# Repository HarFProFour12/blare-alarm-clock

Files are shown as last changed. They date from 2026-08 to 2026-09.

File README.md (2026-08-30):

# BLARE Alarm Clock

This is my custom alarm clock built using a Seeed XIAO ESP32C3 as the brain, with a customizable menu system, real-time clock over wifi, and public domain alarm melodies (Fur Elise, Mountain King, Reveille) played using a passive buzzer.

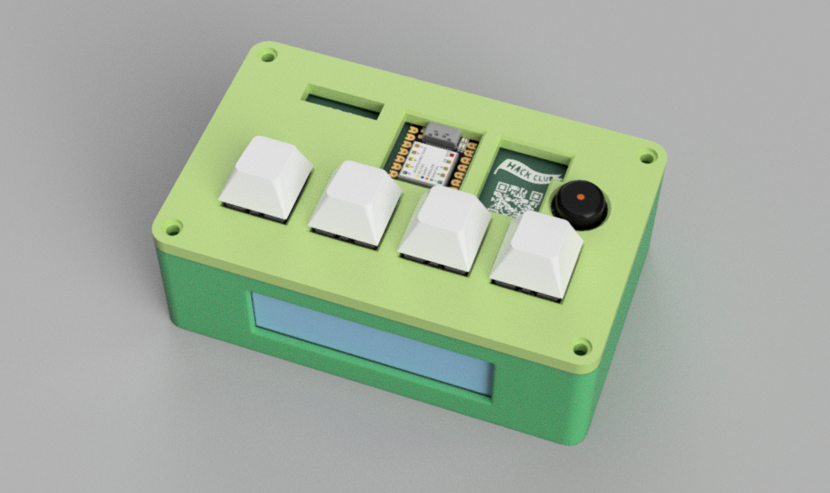
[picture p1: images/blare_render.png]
BLARE (render)


## Features

* RTC using Wi-Fi (NTP)
* Adjustable alarm time
* Changeable alarm sounds
* Adjustable font color
* Button-controlled UI
*  2.25in TFT Screen

## UI

The UI is designed using simple menus so it's easier to navigate using only four buttons (enter, back, up, down). 

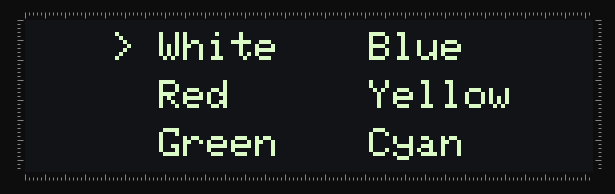
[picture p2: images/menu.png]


The Home screen displays the current time.

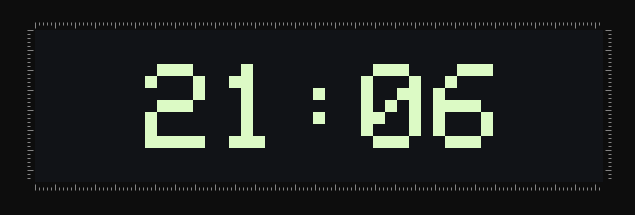
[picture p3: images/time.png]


The Settings menu currently has:

* Alarm Time
* Alarm Sound
* Font Color

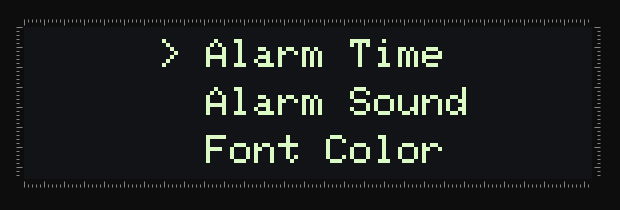
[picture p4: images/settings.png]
Settings Page UI


## How It Works

The clock is controlled by a Seeed XIAO ESP32C3. On startup, it connects to the wifi and get the current time through NTP, since I couldn't use an RTC module (all available GPIO pins were already being used). The current time is displayed on the Home screen, and the user can set the alarm time through the Settings menu. When the current time is the same as the alarm time, the selected melody is played using the piezo buzzer.

## Hardware

The current hardware includes the following components:

* Seeed XIAO ESP32C3
* 2.25in TFT Screen (ST7789 driver)
* 4 pushbuttons
* Passive piezo buzzer

## Schematic & Hardware Wiring

The board uses the XIAO ESP32-C3's D0–D10 pins for all peripherals:

* D0–D3: pushbuttons (enter, back, up, down)
* D4–D6, D8–D10: TFT screen (DC, CS, BL, RST, SCL, SDA)
* D7: buzzer

All 11 available GPIOs are used, leaving no free pins for other components such as an RTC module.

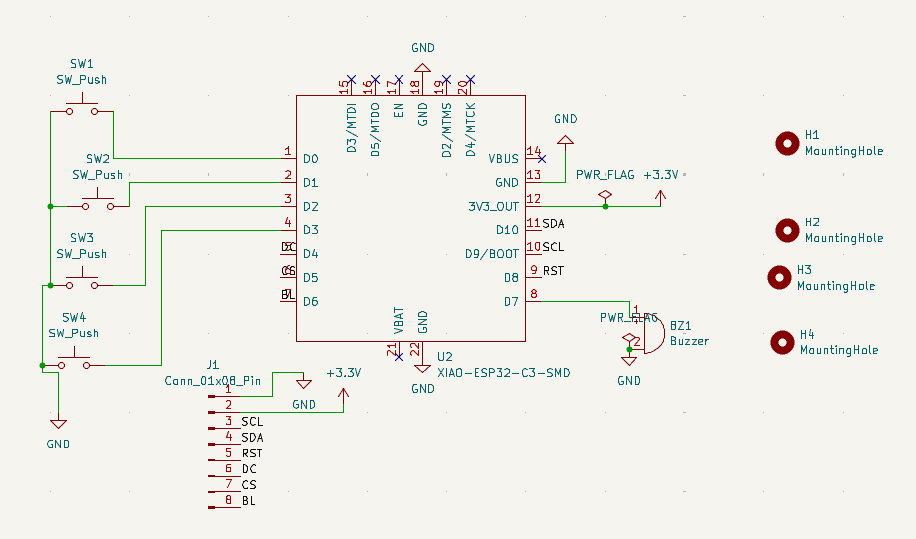
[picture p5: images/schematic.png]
Schematic


The PCB was designed in KiCad, with the four pushbuttons placed alongside the screen for easy access.

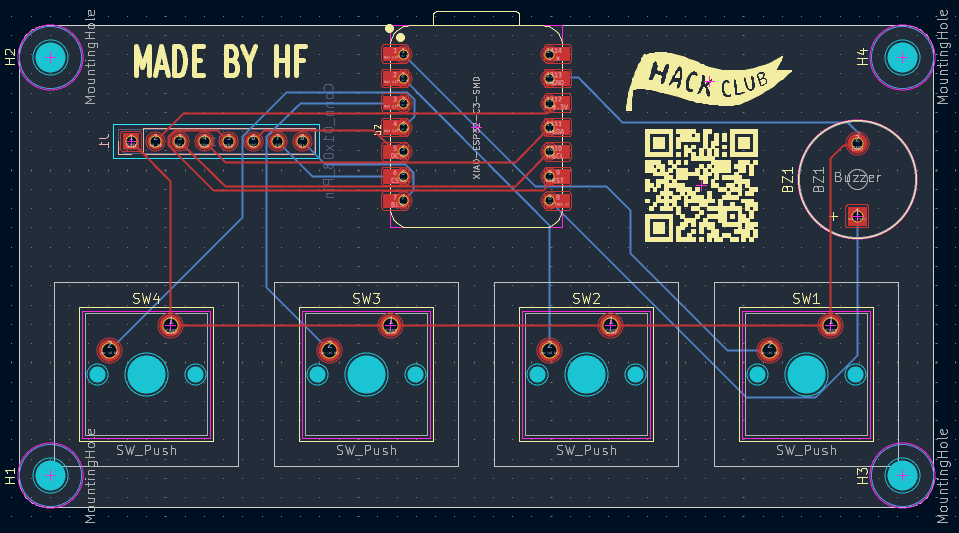
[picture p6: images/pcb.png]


## Project Structure

```text
BLARE/
├── main.ino
└── wifi_codes.h
```

## Current Status

The project is still in the making process.

What I've done so far:

* Basic TFT interface
* Home screen with live clock
* Menu navigation
* Settings screen
* Alarm time adjustment
* Font color adjustment
* Alarm sound selection
* Time sync over wifi
* Alarm trigger logic
* Snooze/dismiss handling

I have left to do:

* Hardware testing on the assembled PCB

## Design

The UI layout was designed using **lopaka.app**, an online graphic design tool for microcontroller screens, before being integrated into the Arduino sketch.

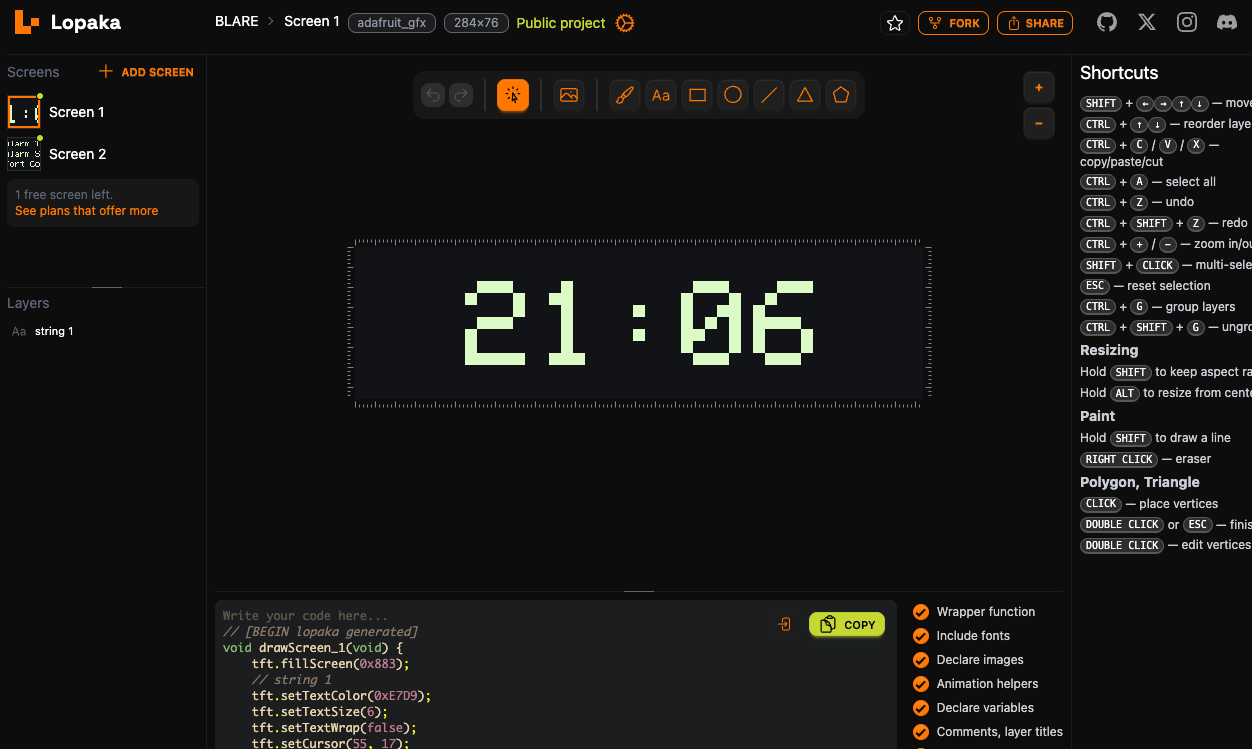
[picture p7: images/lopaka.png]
Lopaka UI Design


## Built With

* Arduino (C++)
* ESP32
* Adafruit_GFX / Adafruit_ST7789 (Arduino Libraries)
* lopaka.app
* KiCad

## AI Usage

I used AI, mainly for:

- Code debugging: fixing errors and syntax issues.
- Alarm sounds: adding public domain melodies (Für Elise, Reveille, In the Hall of the Mountain King) to play through the buzzer.

The actual project design, schematic, PCB layout, UI design, and final assembly were done by me.

---
**Made by Harry Fanouriakis**

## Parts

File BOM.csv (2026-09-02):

Part | Quantity
6×6 mm momentary push button (SW_Push) | 6
Seeed Studio XIAO ESP32-C3-SMD | 1
3.3 V active buzzer | 1
1×8 pin 2.54 mm header | 1
2.25 inch SPI TFT LCD display | 1
M3 Screws | 8
Female to Female Jumper Wires | 8
M3x5x4 Heatset Inserts | 8

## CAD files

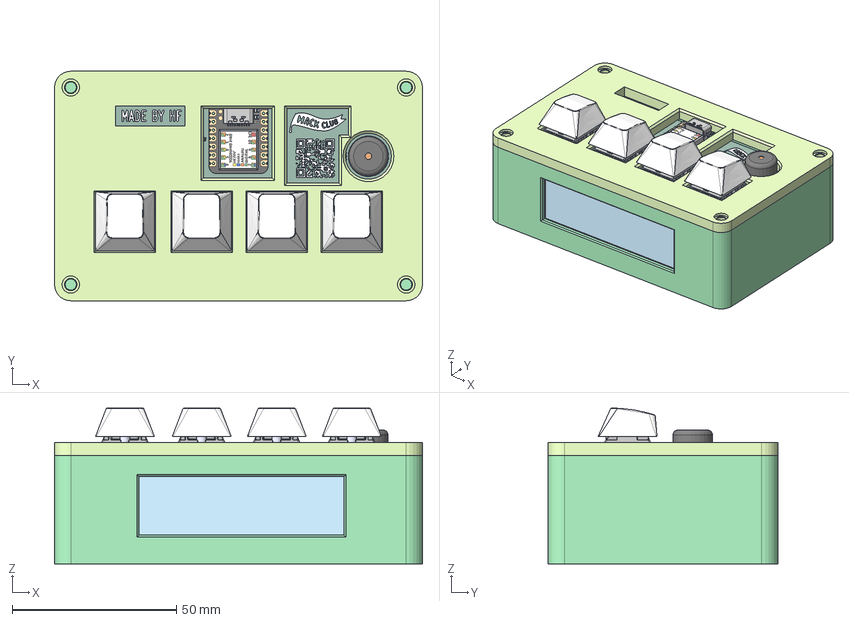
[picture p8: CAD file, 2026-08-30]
CAD/STEPs/Assembled STEPs/BLARE_Assembled.step
112.0 x 69.9 x 47.4 mm

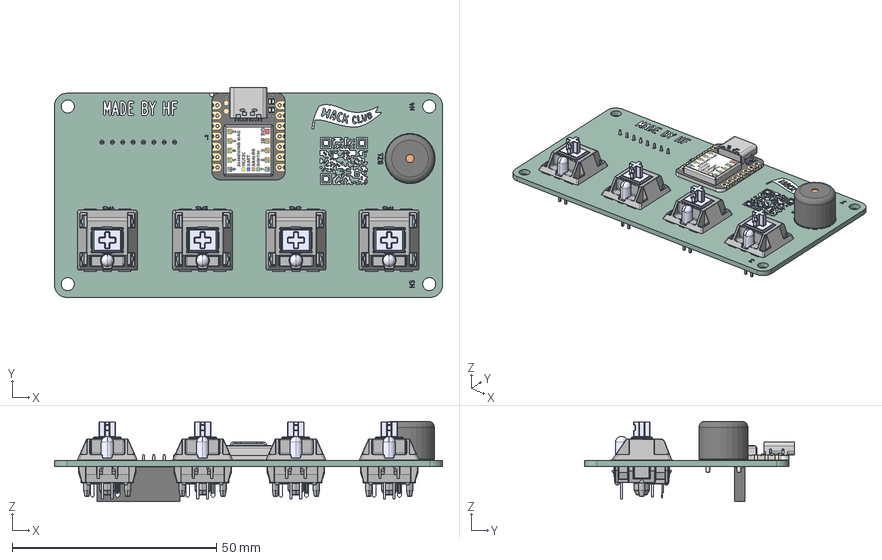
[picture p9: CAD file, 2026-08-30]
CAD/STEPs/Assembled STEPs/pcb_assembled.step
95.0 x 51.4 x 19.7 mm
MX Öá °´¼ü¡ä_¨¹___¡§1 x 4
MX ס סͥ¨¢¨¬_¡§¡顧__ x 4
MXס ϞñLEDLEDLED x 4
MXÖá ÖáÌå µ×²¿ ¦Ì¡Á2__Ä¬ÈÏ_¨¢2____¨¨_ x 4
֫½ğ__Ĭɏ__¨¨_ x 4
Buzzer_12x95RM76
PinSocket_1x08_P2.54mm_Vertical
blare-unsaved-export-SRTC6P_silkscreen x 2
blare-unsaved-export-SRTC6P_PCB

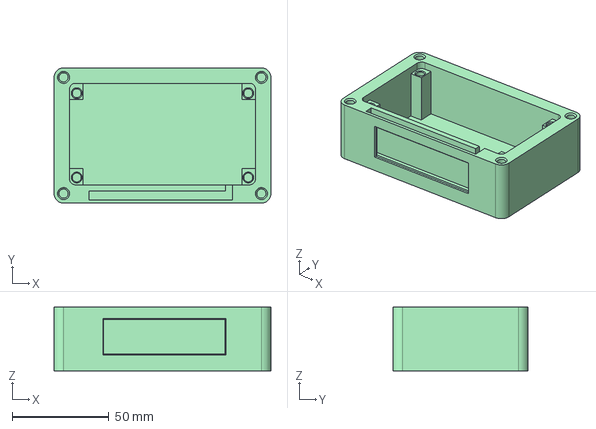
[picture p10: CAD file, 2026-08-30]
CAD/STEPs/Parts STEPs/main_enclosure.step
112.0 x 69.9 x 33.0 mm

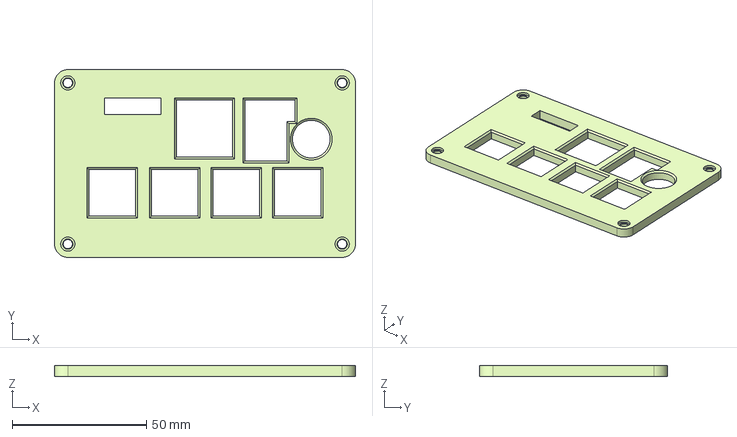
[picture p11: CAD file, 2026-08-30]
CAD/STEPs/Parts STEPs/lid.step
112.0 x 69.9 x 4.00 mm

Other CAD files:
CAD/untitled folder/main_enclosure.stl
CAD/untitled folder/lid.stl

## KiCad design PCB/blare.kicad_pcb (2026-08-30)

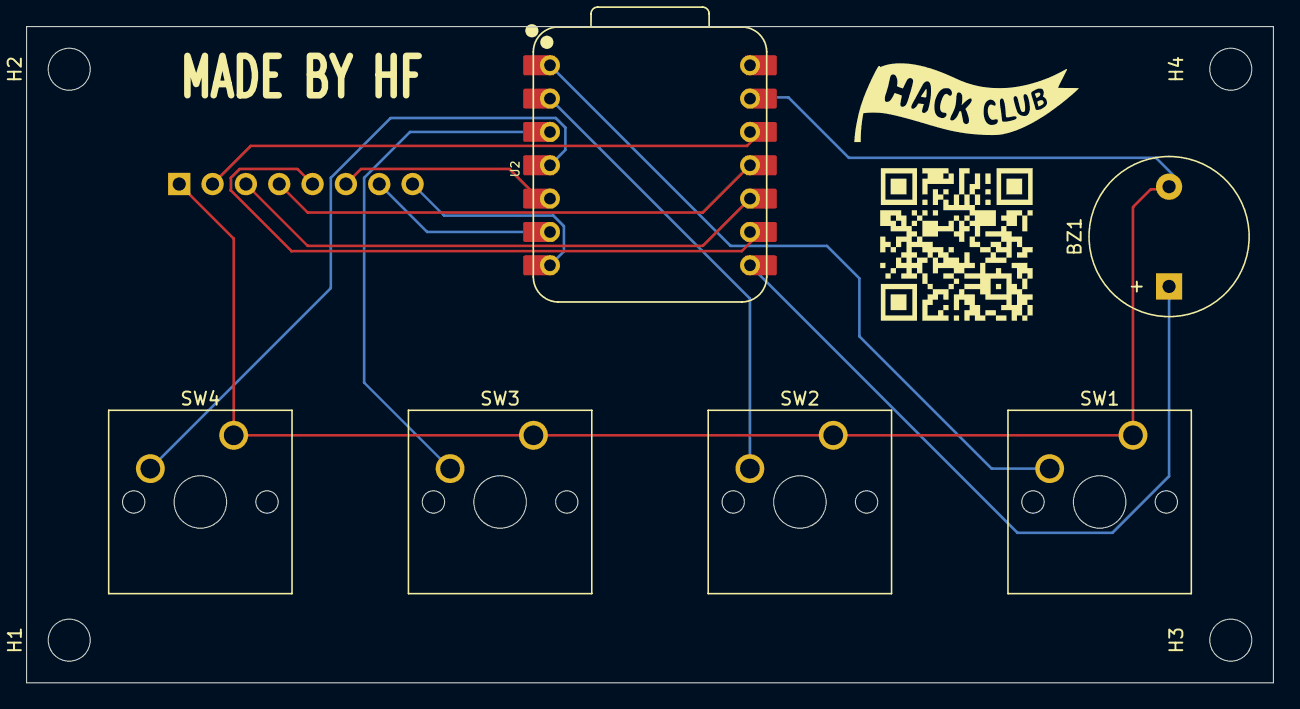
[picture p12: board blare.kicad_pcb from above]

Board: 2 copper layers, 95.0 x 50.0 mm, 11 parts (1 on the bottom side), 13 nets.

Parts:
BZ1: Buzzer; Buzzer_12x9.5RM7.6
H1, H2, H3, H4: MountingHole; MountingHole_3.2mm_M3
J1: Conn_01x08_Pin; PinSocket_1x08_P2.54mm_Vertical
SW1, SW2, SW3, SW4: SW_Push; SW_Cherry_MX_1.00u_PCB
U2: XIAO-ESP32-C3-SMD; XIAO-ESP32-C3-DIP

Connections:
+3.3V: J1.2, U2.12 (3V3_OUT)
/BL: J1.8, U2.7 (D6)
/CS: J1.7, U2.6 (D5)
/DC: J1.6, U2.5 (D4)
/RST: J1.5, U2.9 (D8)
/SCL: J1.3, U2.10 (D9/BOOT)
/SDA: J1.4, U2.11 (D10)
GND: BZ1.2 (-), J1.1, SW1.1, SW2.1, SW3.1, SW4.1, U2.13 (GND)
unnamed: BZ1.1 (+), U2.8 (D7)
unnamed: SW1.2, U2.1 (D0)
unnamed: SW2.2, U2.2 (D1)
unnamed: SW3.2, U2.3 (D2)
unnamed: SW4.2, U2.4 (D3)

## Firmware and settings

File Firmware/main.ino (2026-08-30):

#include <Adafruit_GFX.h>
#include <Adafruit_ST7789.h>
#include <SPI.h>
#include <WiFi.h>
#include <time.h>
#include <wifi_codes.h>

#define TFT_SCLK D9
#define TFT_MOSI D10
#define TFT_RST  D8
#define TFT_DC   D4
#define TFT_CS   D5
#define TFT_BL   D6

#define enterPin D0
#define backPin  D1
#define upPin    D2
#define downPin  D3

#define buzzerPin D7

#define NOTE_B3   247
#define NOTE_C4   262
#define NOTE_C4S  277
#define NOTE_D4   294
#define NOTE_E4   330
#define NOTE_F4   349
#define NOTE_F4S  370
#define NOTE_G4   392
#define NOTE_A4   440
#define NOTE_B4   494
#define NOTE_C5   523
#define NOTE_D5   587
#define NOTE_D5S  622
#define NOTE_E5   659

uint16_t bg_color = 0x883;
uint16_t text_color = 0x07E0;
uint16_t time_size = 6;

int settings_selected = 0;
int color_selected = 0;
int time_selected = 0;
int sounds_selected = 0;

int wake_time_hours = 7;
int wake_time_minutes = 0;

int current_hour = 0;
int current_minute = 0;

bool alarmRinging = false;
unsigned long snoozeUntil = 0;
unsigned long lastSnoozePress = 0;
int snoozeMinutes = 5;

const char* colorNames[6] = { "White", "Red", "Green", "Blue", "Yellow", "Cyan" };
uint16_t colorValues[6] = {
  0xFFFF, // White
  0xF800, // Red
  0x07E0, // Green
  0x001F, // Blue
  0xFFE0, // Yellow
  0x07FF  // Cyan
};

int colorX[6] = { 43, 43, 43, 148, 148, 148 };
int colorY[6] = { 6, 30, 54, 6, 30, 54 };

bool alarmFiredThisMinute = false;

// Für Elise
int furEliseNotes[] = { NOTE_E5, NOTE_D5S, NOTE_E5, NOTE_D5S, NOTE_E5, NOTE_B4, NOTE_D5, NOTE_C5, NOTE_A4 };
int furEliseDurations[] = { 200, 200, 200, 200, 200, 200, 200, 200, 400 };
int furEliseLength = 9;

// Reveille
int reveilleNotes[] = { NOTE_C4, NOTE_C4, NOTE_C4, NOTE_E4, NOTE_G4, NOTE_C5, NOTE_G4, NOTE_E4, NOTE_C4 };
int reveilleDurations[] = { 150, 150, 300, 300, 300, 400, 300, 300, 500 };
int reveilleLength = 9;

// In the Hall of the Mountain King
int mountainKingNotes[] = { NOTE_B3, NOTE_C4S, NOTE_D4, NOTE_E4, NOTE_F4S, NOTE_G4, NOTE_F4S, NOTE_E4, NOTE_D4, NOTE_C4S, NOTE_B3 };
int mountainKingDurations[] = { 300, 300, 300, 300, 300, 300, 200, 200, 200, 200, 400 };
int mountainKingLength = 11;

enum Screens {
    TIME,
    SETTINGS,
    ALARM_TIME,
    ALARM_SOUND,
    FONT_COLOR
};


Screens currentScreen = TIME;
Screens lastDrawnScreen = SETTINGS;
int lastDrawnSelection = -1;

class MyST7789 : public Adafruit_ST7789 {
public:
  MyST7789(int8_t cs, int8_t dc, int8_t mosi, int8_t sclk, int8_t rst)
    : Adafruit_ST7789(cs, dc, mosi, sclk, rst) {}
  void setOffsets(uint8_t col, uint8_t row) {
    _colstart = _colstart2 = col;
    _rowstart = _rowstart2 = row;
  }
};

MyST7789 tft(TFT_CS, TFT_DC, TFT_MOSI, TFT_SCLK, TFT_RST);

void setup() {
    Serial.begin(115200); // lets the board talk to your computer
    pinMode(TFT_BL, OUTPUT); // Set the backlight pin mode, or just wire it to 3.3V
    digitalWrite(TFT_BL, LOW); // Turns the backlight ON, for some reason this screen is active Low, so setting it to LOW is really HIGH

    tft.init(76, 284); // Our panel size (portrait)
    tft.setOffsets(82, 18); // Offsets for the weird resolution
    tft.invertDisplay(false); // Invert the colors (This display is flipped from normal)
    tft.setRotation(1); // Landscape, if it's upside down use 3!
    Serial.println("TFT Initialized!");

    tft.fillScreen(bg_color); // clear the screen

    pinMode(enterPin, INPUT_PULLUP);
    pinMode(backPin, INPUT_PULLUP);
    pinMode(upPin, INPUT_PULLUP);
    pinMode(downPin, INPUT_PULLUP); 

    WiFi.begin(SSID, PASSWORD);
    while (WiFi.status() != WL_CONNECTED) delay(500);
}

void loop() {
    struct tm timeinfo;
    if (getLocalTime(&timeinfo)) {
        current_hour = timeinfo.tm_hour;
        current_minute = timeinfo.tm_min;
    }

    if (wake_time_hours == current_hour && wake_time_minutes == current_minute) {
        if (!alarmFiredThisMinute) {
            alarmFiredThisMinute = true;
            alarmRinging = true;
        }
    }
    else {
        alarmFiredThisMinute = false;
    }

    if (snoozeUntil != 0 && millis() >= snoozeUntil) {
        snoozeUntil = 0;
        alarmRinging = true;
    }

    if (alarmRinging) {
        handleRingingAlarm();
    }
    bool screenChanged = (currentScreen != lastDrawnScreen);

    switch (currentScreen) {

        case TIME: {
            if (screenChanged) {
                drawTime();
                lastDrawnScreen = currentScreen;
            }
            if (digitalRead(enterPin) == LOW) {
                currentScreen = SETTINGS;
                settings_selected = 0;
            }
            break;
        }

        case SETTINGS: {
            if (digitalRead(downPin) == LOW) settings_selected++;
            if (digitalRead(upPin) == LOW) settings_selected--;
            if (settings_selected > 2) settings_selected = 0;
            if (settings_selected < 0) settings_selected = 2;

            if (screenChanged || settings_selected != lastDrawnSelection) {
                drawSettings();
                lastDrawnScreen = currentScreen;
                lastDrawnSelection = settings_selected;
            }

            if (digitalRead(enterPin) == LOW) {
                if (settings_selected == 0) currentScreen = ALARM_TIME;
                if (settings_selected == 1) currentScreen = ALARM_SOUND;
                if (settings_selected == 2) currentScreen = FONT_COLOR;
                lastDrawnSelection = -1;
            }

            if (digitalRead(backPin) == LOW) {
                currentScreen = TIME;
            }
            break;
        }

        case ALARM_SOUND: {
            if (digitalRead(downPin) == LOW) sounds_selected++;
            if (digitalRead(upPin) == LOW) sounds_selected--;
            if (sounds_selected > 2) sounds_selected = 0;
            if (sounds_selected < 0) sounds_selected = 2;

            if (screenChanged || sounds_selected != lastDrawnSelection) {
                drawAlarmSound();
                lastDrawnScreen = currentScreen;
                lastDrawnSelection = sounds_selected;
            }

            if (digitalRead(enterPin) == LOW) {
                if (sounds_selected == 0) playMelody(furEliseNotes, furEliseDurations, furEliseLength);
                if (sounds_selected == 1) playMelody(reveilleNotes, reveilleDurations, reveilleLength);
                if (sounds_selected == 2) playMelody(mountainKingNotes, mountainKingDurations, mountainKingLength);
            }

            if (digitalRead(backPin) == LOW) {
                currentScreen = SETTINGS;
                lastDrawnSelection = -1;
            }
            break;
        }

        case ALARM_TIME: {
            if (digitalRead(downPin) == LOW) {
                if (time_selected == 0) wake_time_hours--;
                else wake_time_minutes--;
            }
            if (digitalRead(upPin) == LOW) {
                if (time_selected == 0) wake_time_hours++;
                else wake_time_minutes++;
            }

            if (wake_time_hours > 23) wake_time_hours = 0;
            if (wake_time_hours < 0) wake_time_hours = 23;
            if (wake_time_minutes > 59) wake_time_minutes = 0;
            if (wake_time_minutes < 0) wake_time_minutes = 59;

            if (digitalRead(enterPin) == LOW) {
                time_selected++;
                if (time_selected > 1) time_selected = 0;
            }

            drawAlarmTime();

            if (digitalRead(backPin) == LOW) {
                currentScreen = SETTINGS;
                lastDrawnSelection = -1;
            }
            break;
        }
        case FONT_COLOR: {
            if (digitalRead(downPin) == LOW) color_selected++;
            if (digitalRead(upPin) == LOW) color_selected--;
            if (color_selected > 5) color_selected = 0;
            if (color_selected < 0) color_selected = 5;

            if (screenChanged || color_selected != lastDrawnSelection) {
                drawFontColor();
                lastDrawnScreen = currentScreen;
                lastDrawnSelection = color_selected;
            }

            if (digitalRead(enterPin) == LOW) {
                if (color_selected == 0) text_color = 0xFFFF; // White
                if (color_selected == 1) text_color = 0xF800; // Red
                if (color_selected == 2) text_color = 0x07E0; // Green
                if (color_selected == 3) text_color = 0x001F; // Blue
                if (color_selected == 4) text_color = 0xFFE0; // Yellow
                if (color_selected == 5) text_color = 0x07FF; // Cyan
                lastDrawnSelection = -1; // force redraw so preview updates immediately
            }

            if (digitalRead(backPin) == LOW) {
                currentScreen = SETTINGS;
                lastDrawnSelection = -1;
            }
            break;
            }
    }
    delay(150);
}

void drawTime() {
    tft.fillScreen(bg_color);

    // Time
    tft.setTextColor(text_color);
    tft.setTextSize(6);
    tft.setTextWrap(false);
    tft.setCursor(55, 17);

    char buf[6];
    sprintf(buf, "%02d:%02d", current_hour, current_minute);
    tft.print(buf);
}

void getTime() {
    
}

void playMelody(int notes[], int durations[], int length) {
  for (int i = 0; i < length; i++) {
    tone(buzzerPin, notes[i], durations[i]);
    delay(durations[i] * 1.3); // gap so notes don't blur together
    noTone(buzzerPin);
  }
}

void handleRingingAlarm() {
    if (sounds_selected == 0) playMelody(furEliseNotes, furEliseDurations, furEliseLength);
    if (sounds_selected == 1) playMelody(reveilleNotes, reveilleDurations, reveilleLength);
    if (sounds_selected == 2) playMelody(mountainKingNotes, mountainKingDurations, mountainKingLength);

    unsigned long waitStart = millis();
    while (millis() - waitStart < 5000) {
        if (digitalRead(enterPin) == LOW) {
            unsigned long now = millis();

            if (now - lastSnoozePress < 500) {
                alarmRinging = false;
                lastSnoozePress = 0;
                return;
            }

            lastSnoozePress = now;
            delay(200);
        }
    }
    if (lastSnoozePress != 0) {
        snoozeUntil = millis() + (snoozeMinutes * 60000UL);
        alarmRinging = false;
        lastSnoozePress = 0;
    }
    else {

    }
}

void drawSettings() {
    tft.fillScreen(bg_color);
    tft.setTextColor(text_color);
    tft.setTextSize(2);
    tft.setTextWrap(false);

    tft.setCursor(71, 6);
    tft.print(settings_selected == 0 ? "> Alarm time" : "  Alarm time");

    tft.setCursor(71, 30);
    tft.print(settings_selected == 1 ? "> Alarm sound" : "  Alarm sound");

    tft.setCursor(71, 54);
    tft.print(settings_selected == 2 ? "> Font color" : "  Font color");
}

void drawAlarmTime() {
  tft.fillScreen(bg_color);
  tft.setTextColor(text_color);
  tft.setTextSize(6);
  tft.setTextWrap(false);
  tft.setCursor(55, 17);

  char buf[6];
  sprintf(buf, "%02d:%02d", wake_time_hours, wake_time_minutes);
  tft.print(buf);

  tft.setTextSize(2);
  tft.setCursor(55, 60);
  tft.print(time_selected == 0 ? "^^^" : "   ^^^");
}

void drawFontColor() {
  tft.fillScreen(bg_color);
  tft.setTextColor(text_color);
  tft.setTextSize(2);
  tft.setTextWrap(false);

  for (int i = 0; i < 6; i++) {
    tft.setCursor(colorX[i], colorY[i]);
    tft.print(color_selected == i ? "> " : "  ");
    tft.print(colorNames[i]);
  }
}

void drawAlarmSound() {
    tft.fillScreen(bg_color);
    tft.setTextColor(text_color);
    tft.setTextSize(2);
    tft.setTextWrap(false);

    tft.setCursor(71, 6);
    tft.print(sounds_selected == 0 ? "> Fur Elise" : "  Fur Elise");

    tft.setCursor(71, 30);
    tft.print(sounds_selected == 1 ? "> Reveille" : "  Reveille");

    tft.setCursor(71, 54);
    tft.print(sounds_selected == 2 ? "> Mountain King" : "  Mountain King");
}
